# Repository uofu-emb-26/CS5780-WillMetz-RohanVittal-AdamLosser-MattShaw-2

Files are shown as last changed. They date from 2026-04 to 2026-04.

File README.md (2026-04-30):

# CS5780 Final Project
# Nixie Tube Sound Meter

## Rohan Vittal, Will Metz, Adam Losser, and Matt Shaw 

A nixie tube driver that displays real-time microphone loudness as a percentage (0–100) across four ZM1000 nixie tubes. Audio is sampled via an onboard microphone through the STM32's ADC, processed into a loudness percentage, and transmitted over UART to a PC while simultaneously driving the nixie display.

## System Overview:
The system consists of three physical boards:

- STM32F072 Discovery — microcontroller, ADC microphone input, UART output, GPIO drive
- Custom PCB — contains K155ID1 (К155ИД1) BCD driver ICs, HV power distribution, and connectors
- [HV Power Board](https://ebay.us/m/Hubveg) — MAX1771 boost converter (160–210V output), 5V logic input
See [BOM](./BOM.md) for a detailed list of components.

The STM32 extracts digits from the loudness percentage and writes 4-bit BCD values to GPIO pins. Each set of 4 GPIO pins drives one K155ID1 BCD decoder IC, which selects the corresponding cathode on each ZM1000 tube. The anode of each tube is supplied with ~170V.

## Software: 
[mic_test](./mic_test/) contains the code that runs on the STM32. To flash, connect the STM32 discovery to USB, and use the cmake command

```bash
cmake --build build --target mic_test
```
### Software Structure
| File | Description |
|---|---|
| `main.c` | Main loop — ADC sampling, smoothing, UART transmit, nixie write |
| `nixie_drivers.c` | Digit extraction, BCD remapping, GPIO write |
| `adc_mic.c` | ADC initialisation and peak-to-peak measurement |
| `uart.c` | UART3 initialisation and byte transmit |
| `board.c` | SysTick, delay, LED bar (unused) |
| `stm32f0xx_it.c` | SysTick interrupt handler |

### GPIO Pin mappings: 
| Tube | MSB | — | — | LSB |
|---|---|---|---|---|
| Tube 4 (hundreds) | PC9 | PC8 | PC7 | PC6 |
| Tube 3 (tens) | PA11 | PA10 | PA9 | PA8 |
| Tube 2 (ones) | PB11 | PB10 | PB9 | PB8 |
| Tube 1 (tenths) | PB7 | PB6 | PB5 | PB4 |

### BCD Remapping

Due to physical wiring errors on the PCB, a lookup table in firmware remaps intended digits to the correct GPIO pattern:

```c
static const uint8_t digit_map[10] = {
    0b1101, // 0
    0b0001, // 1
    0b1001, // 2
    0b0000, // 3
    0b1110, // 4
    0b0110, // 5
    0b1010, // 6
    0b0010, // 7
    0b1000, // 8
    0b0100  // 9
};
```

## Hardware Notes

- **HV polarity** — the eBay HV power board has reversed polarity output terminals. Verify with a multimeter before connecting to the PCB.
- **HV and logic ground** — must be tied to a common ground, either through the screw terminal or using a breadboard. Separate grounds will prevent cathode current return and the tube will not display any digit.
- **Primer pin** — the ZM1000 primer pin is left floating. A 10MΩ resistor to the anode is recommended per the datasheet for strobed applications but is not required for basic DC operation.
- **USB power** — the micro-USB connector footprint on the PCB was incorrect. It is more reliable to attach 5V power directly by soldering a wire or header on in lieu of the microUSB. 

[fixedSN74141N](./fixedSN74141N/) is a converted KiCAD footprint for the TI SN74141N IC (Identical to the Soviet К155ИД1). 

[nixie_driver](./nixie_driver/) is the KiCAD project for our custom PCB. It takes a 170VDC and 5VDC input, as well as 16 GPIOs for BCD number input. Note that the high voltage and 5V side need to share a common grounding.

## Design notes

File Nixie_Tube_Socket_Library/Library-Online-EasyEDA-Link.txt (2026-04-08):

Library can be found here: https://bit.ly/EasyEDA-SOCKET-LIB

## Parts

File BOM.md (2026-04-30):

# Nixie Tube Driver — Bill of Materials

## Active Components

|Ref  |Description |Value / Part |Qty|Package  |Notes |
|-----|---|---|---|---|---|
|U1 |HV DC-DC Boost Module |MAX1771 |1  |Module |5V in → 170V out|
|U2–U5|BCD-to-Decimal Nixie Driver|SN74141 or K155ID1|4  |DIP-16 |One per tube |
|MCU  |Microcontroller Board |STM32 Discovery |1  |Dev board|Already owned |

-----

## Passive Components

|Ref  |Description |Value |Qty|Package |Notes |
|-----|---|---|---|---|---|
|R1–R4|Anode current-limiting resistor|12kΩ, 1W  |4  |Through-hole or 2512 SMD |1W rating for power dissipation at 170V. One per tube anode.|
|C1–C4|VCC decoupling cap per SN74141 |100nF, 50V|4  |0805 SMD or through-hole |Place as close to each IC VCC pin as possible |
|C7 |HV output decoupling |10µF, 250V|1  |Electrolytic, rated >200V|On 170V rail, near anode resistors |

-----

## Connectors 

|Ref |Description |Part |Qty|Notes |
|---|---|---|---|---|
|J1 |USB input connector|USB  Micro-B |1  |5V power input to PCB |
|J2 |STM32 GPIO header  |2.54mm pin header |1  |16-pin minimum (4 pins × 4 tubes) |
|J3 |HV test point |2-pin header or TP pad |1  |For bench verification of 170V rail |
|J4 |HV input screw terminal | 1x2 3.5mm screw terminal | 1 | |
|J5-J23 | Pin sockets| 1x5 and 1x2 2.54mm pin sockets| 8 ea. | Sockets for nixie tubes|

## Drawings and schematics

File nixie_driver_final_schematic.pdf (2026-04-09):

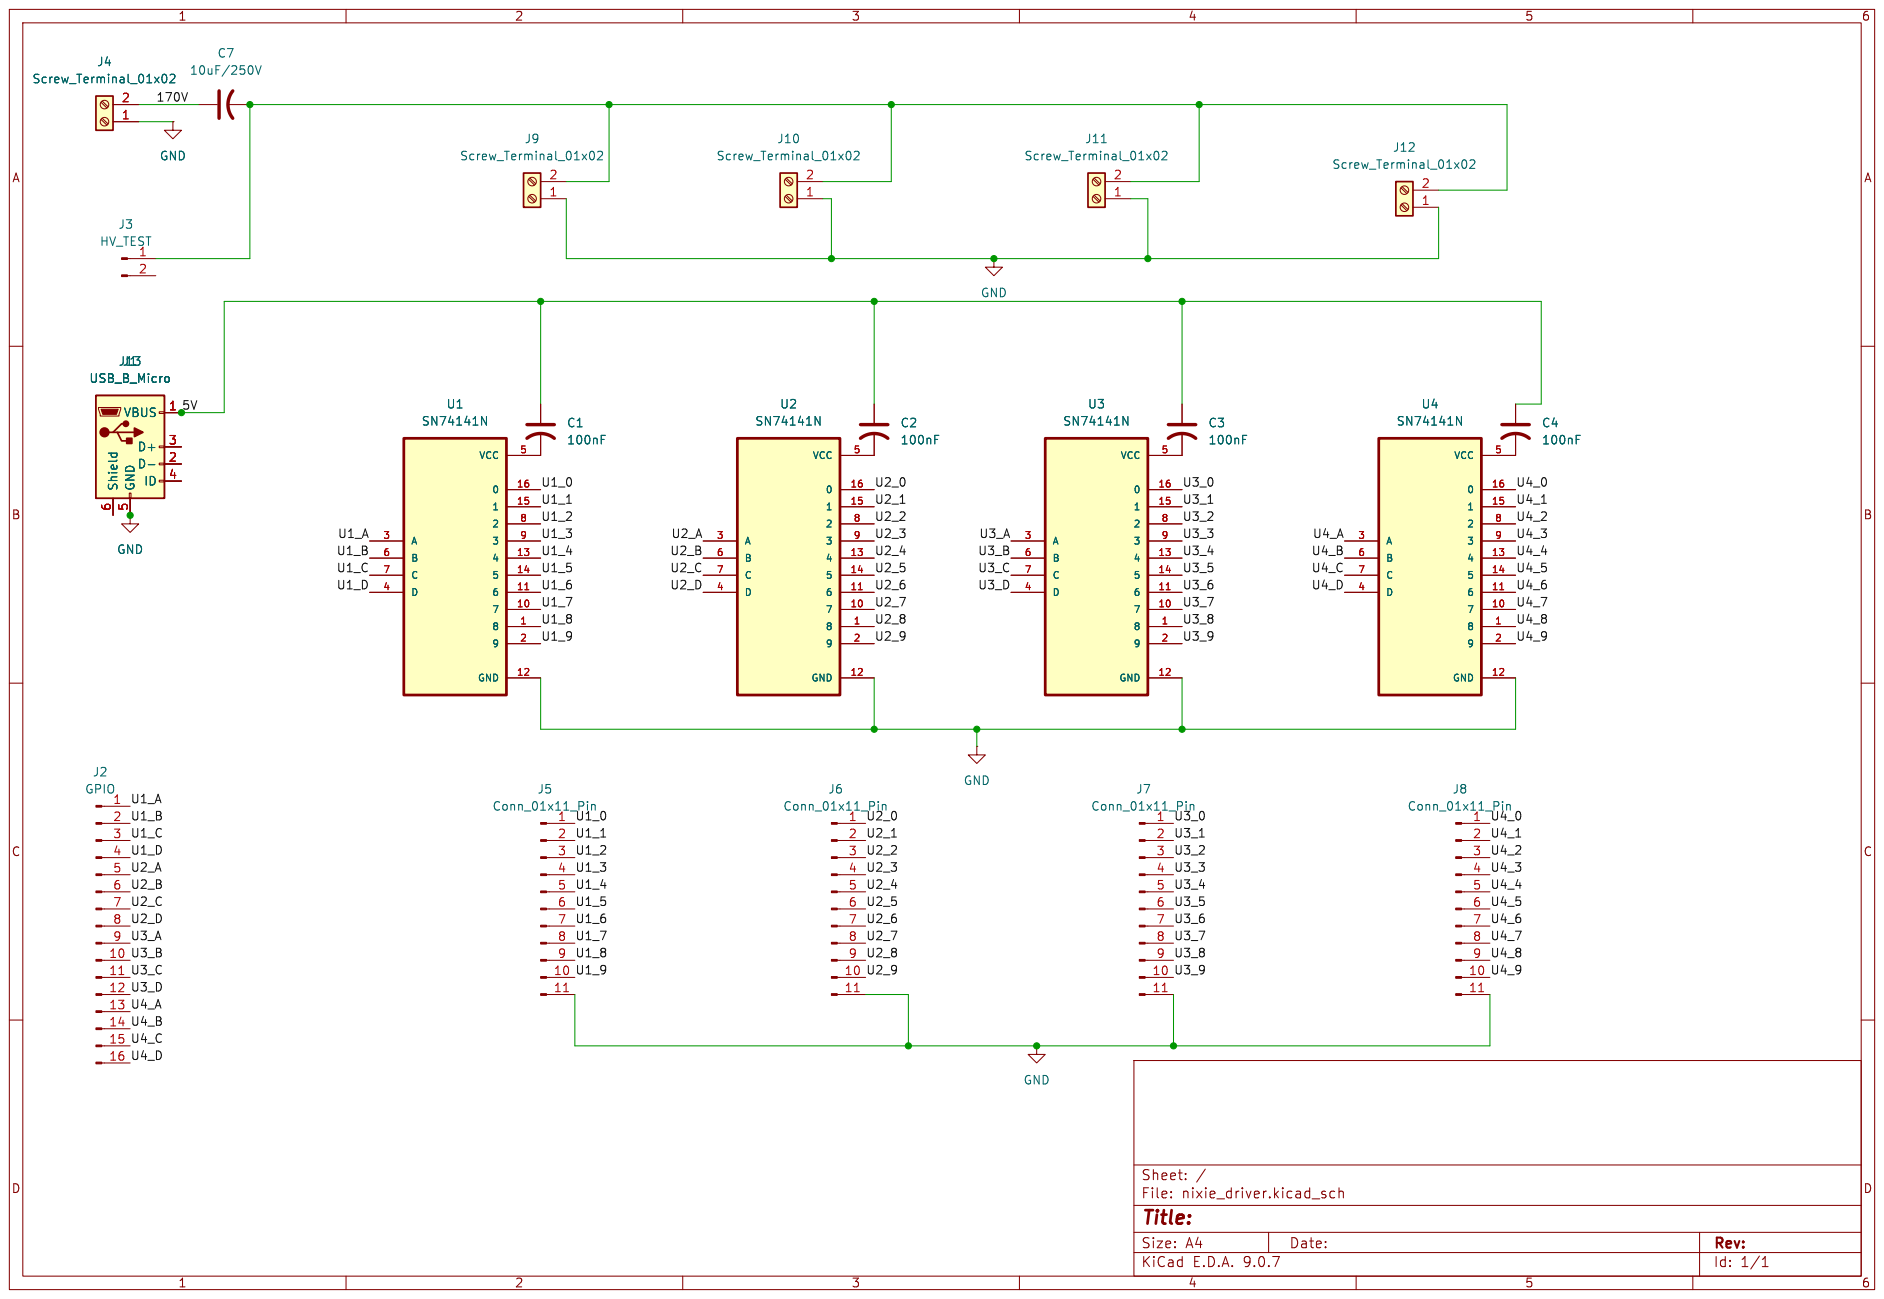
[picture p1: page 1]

Id: 1/1 Title: File: nixie_driver.kicad_sch Sheet: / Shield

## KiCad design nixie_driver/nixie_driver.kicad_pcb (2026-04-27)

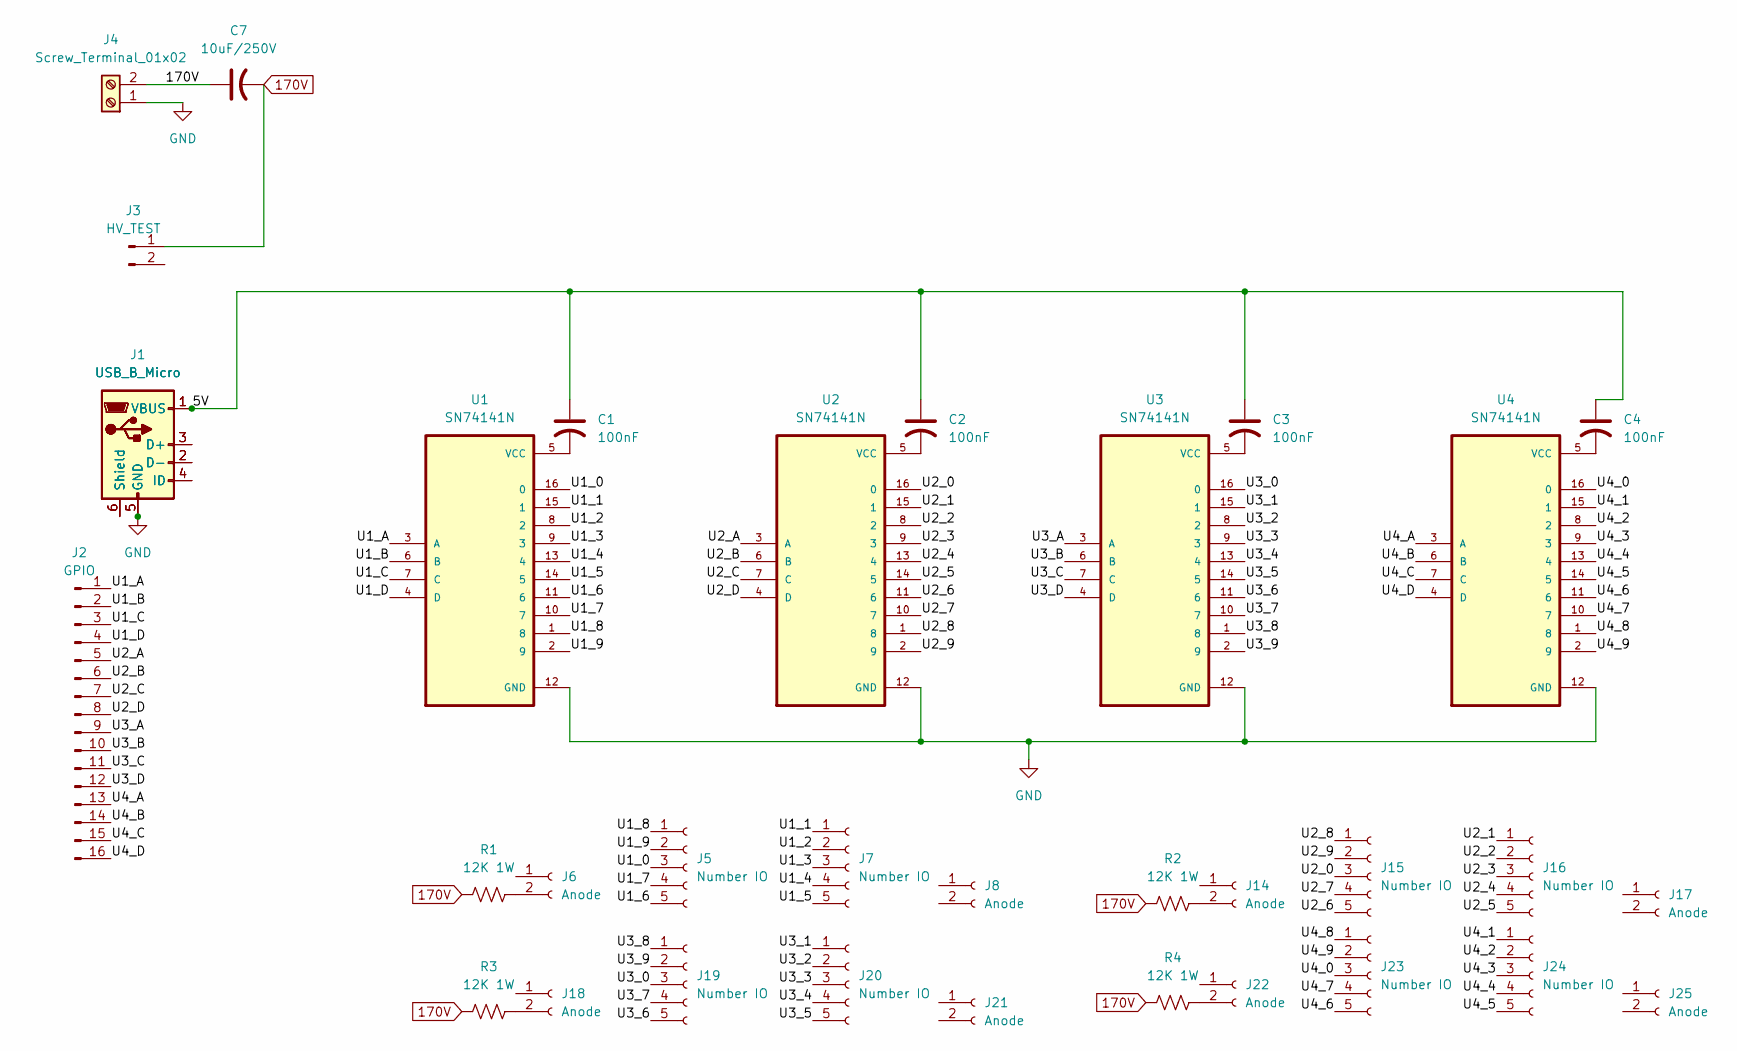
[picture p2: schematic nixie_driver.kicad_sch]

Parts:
C1, C2, C3, C4: 100nF; C_0805_2012Metric_Pad1.18x1.45mm_HandSolder
C7: 10uF/250V; CP_Radial_D8.0mm_P3.50mm
J1: USB_B_Micro; USB_Micro-AB_Molex_47590-0001
J2: GPIO; PinHeader_1x16_P2.54mm_Vertical
J3: HV_TEST; PinHeader_1x02_P2.54mm_Vertical
J4: Screw_Terminal_01x02; TerminalBlock_MetzConnect_Type011_RT05502HBLC_1x02_P5.00mm_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
J5, J7, J15, J16, J19, J20, J23, J24: Number IO; PinSocket_1x05_P2.54mm_Vertical
J6, J8, J14, J17, J18, J21, J22, J25: Anode; PinSocket_1x02_P2.54mm_Vertical
J13: USB_B_Micro
R1, R2, R3, R4: 12K 1W; R_Axial_DIN0414_L11.9mm_D4.5mm_P20.32mm_Horizontal
U1, U2, U3, U4: SN74141N; DIP762W46P254L2134H508Q16

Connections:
170V: C7.1, C7.2, J3.1, J4.2, R1.1, R2.1, R3.1, R4.1
/5V: C1.1, C2.1, C3.1, C4.1, J1.1 (VBUS), J13.1 (VBUS)
/U1_0: J5.3, U1.16 (0)
/U1_1: J7.1, U1.15 (1)
/U1_2: J7.2, U1.8 (2)
/U1_3: J7.3, U1.9 (3)
/U1_4: J7.4, U1.13 (4)
/U1_5: J7.5, U1.14 (5)
/U1_6: J5.5, U1.11 (6)
/U1_7: J5.4, U1.10 (7)
/U1_8: J5.1, U1.1 (8)
/U1_9: J5.2, U1.2 (9)
/U1_A: J2.1, U1.3 (A)
/U1_B: J2.2, U1.6 (B)
/U1_C: J2.3, U1.7 (C)
/U1_D: J2.4, U1.4 (D)
/U2_0: J15.3, U2.16 (0)
/U2_1: J16.1, U2.15 (1)
/U2_2: J16.2, U2.8 (2)
/U2_3: J16.3, U2.9 (3)
/U2_4: J16.4, U2.13 (4)
/U2_5: J16.5, U2.14 (5)
/U2_6: J15.5, U2.11 (6)
/U2_7: J15.4, U2.10 (7)
/U2_8: J15.1, U2.1 (8)
/U2_9: J15.2, U2.2 (9)
/U2_A: J2.5, U2.3 (A)
/U2_B: J2.6, U2.6 (B)
/U2_C: J2.7, U2.7 (C)
/U2_D: J2.8, U2.4 (D)
/U3_0: J19.3, U3.16 (0)
/U3_1: J20.1, U3.15 (1)
/U3_2: J20.2, U3.8 (2)
/U3_3: J20.3, U3.9 (3)
/U3_4: J20.4, U3.13 (4)
/U3_5: J20.5, U3.14 (5)
/U3_6: J19.5, U3.11 (6)
/U3_7: J19.4, U3.10 (7)
/U3_8: J19.1, U3.1 (8)
/U3_9: J19.2, U3.2 (9)
/U3_A: J2.9, U3.3 (A)
/U3_B: J2.10, U3.6 (B)
/U3_C: J2.11, U3.7 (C)
/U3_D: J2.12, U3.4 (D)
/U4_0: J23.3, U4.16 (0)
/U4_1: J24.1, U4.15 (1)
/U4_2: J24.2, U4.8 (2)
/U4_3: J24.3, U4.9 (3)
/U4_4: J24.4, U4.13 (4)
/U4_5: J24.5, U4.14 (5)
/U4_6: J23.5, U4.11 (6)
/U4_7: J23.4, U4.10 (7)
/U4_8: J23.1, U4.1 (8)
/U4_9: J23.2, U4.2 (9)
/U4_A: J2.13, U4.3 (A)
/U4_B: J2.14, U4.6 (B)
/U4_C: J2.15, U4.7 (C)
/U4_D: J2.16, U4.4 (D)
GND: J1.5 (GND), J4.1, J13.5 (GND), U1.12 (GND), U2.12 (GND), U3.12 (GND), U4.12 (GND)
unnamed: J1.3 (D+), J13.3 (D+)
unnamed: J1.2 (D-), J13.2 (D-)
unnamed: J1.4 (ID), J13.4 (ID)
unnamed: J1.6 (Shield), J13.6 (Shield)
unnamed: J6.2, R1.2
unnamed: J14.2, R2.2
unnamed: J18.2, R3.2
unnamed: J22.2, R4.2
unnamed: C1.2, U1.5 (VCC)
unnamed: C2.2, U2.5 (VCC)
unnamed: C3.2, U3.5 (VCC)
unnamed: C4.2, U4.5 (VCC)

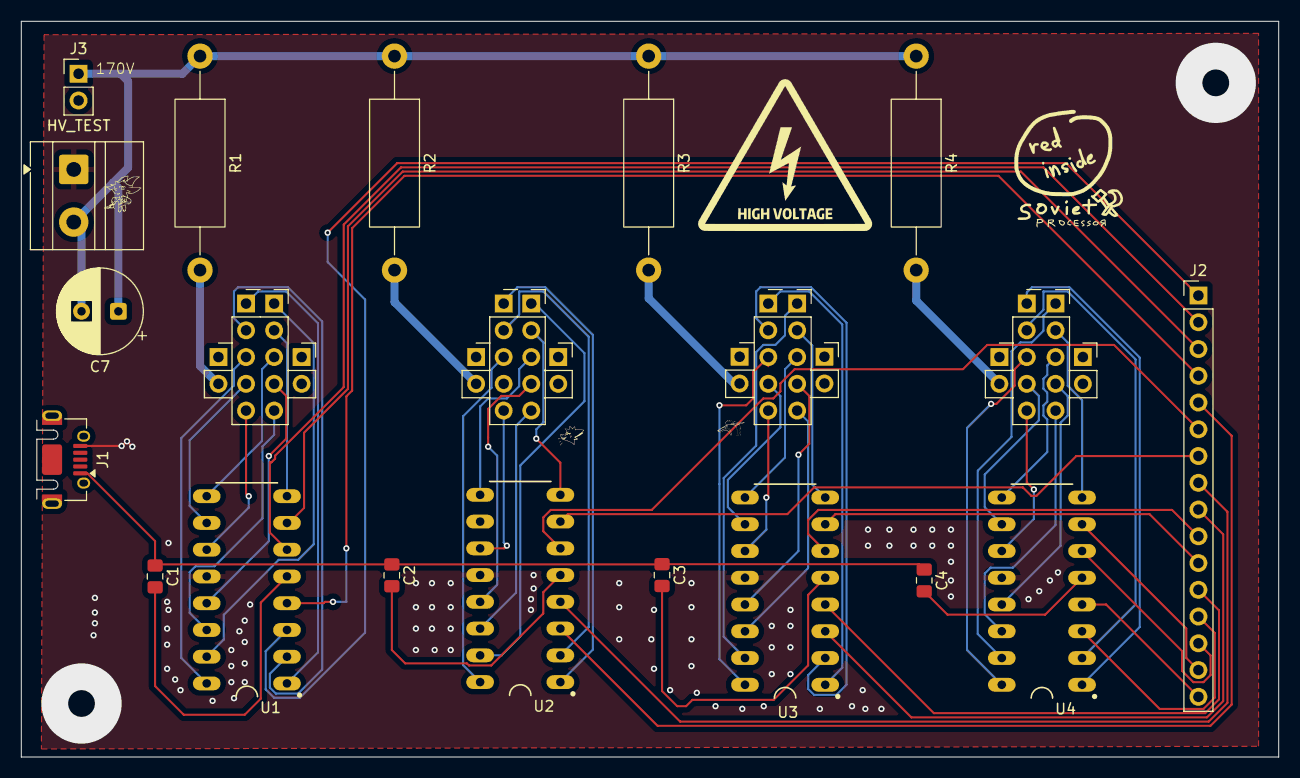
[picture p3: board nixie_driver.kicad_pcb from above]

Board: 2 copper layers, 119.4 x 69.8 mm, 33 parts (0 on the bottom side), 67 nets.

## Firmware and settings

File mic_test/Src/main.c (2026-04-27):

#include <stdint.h>
#include "adc_mic.h"
#include "app_config.h"
#include "board.h"
#include "stm32f0xx.h"
#include "stm32f0xx_hal.h"
#include "stm32f0xx_hal_gpio.h"
#include "uart.h"
#include "nixie_drivers.h"

static uint16_t apply_noise_floor(uint16_t level)
{
    if (level <= MIC_NOISE_FLOOR_COUNTS)
    {
        return 0u;
    }

    return (uint16_t)(level - MIC_NOISE_FLOOR_COUNTS);
}

static uint8_t level_to_led_count(uint16_t level)
{
    if (level >= MIC_LED4_THRESHOLD)
    {
        return 4u;
    }
    if (level >= MIC_LED3_THRESHOLD)
    {
        return 3u;
    }
    if (level >= MIC_LED2_THRESHOLD)
    {
        return 2u;
    }
    if (level >= MIC_LED1_THRESHOLD)
    {
        return 1u;
    }
    return 0u;
}

volatile uint16_t g_mic_peak_to_peak_raw = 0u;
volatile uint16_t g_mic_peak_to_peak_filtered = 0u;
volatile uint16_t g_mic_level_smoothed = 0u;
volatile uint8_t g_led_count = 0u;

int main(void)
{
    uint16_t smoothed_level = 0u;

    board_init();
    mic_init();

    HAL_Init();
    uart_init();
    init_tube_gpios();

    uint8_t previous_percentage = 0; // hold the previously transmitted value


    

    while (1)
    {

        uint8_t percentage_buffer[BUFFER_SIZE] = {0};

        for (uint32_t buffer_count = 0; buffer_count < BUFFER_SIZE; buffer_count++) // loop to fill buffer with 20 values before transmitting
        {

        uint16_t raw_level = mic_measure_peak_to_peak(MIC_SAMPLE_WINDOW);
        uint16_t filtered_level = apply_noise_floor(raw_level);

        smoothed_level = (uint16_t)(((uint32_t)smoothed_level * APP_SMOOTHING_NUMERATOR +
                                     (uint32_t)filtered_level) /
                                    APP_SMOOTHING_DENOMINATOR);

        g_mic_peak_to_peak_raw = raw_level;
        g_mic_peak_to_peak_filtered = filtered_level;
        if (filtered_level > g_mic_level_smoothed) {
            g_mic_level_smoothed = filtered_level;
        } else {
            g_mic_level_smoothed = (uint16_t)(((3u * g_mic_level_smoothed) + filtered_level) / 4u);
        }
        g_led_count = level_to_led_count(smoothed_level);

        //board_led_bar_set(g_led_count);

        // convert filtered level into the range 0 to 100 (a loudness percentage)
            uint32_t interpolation_input = (uint32_t)filtered_level; // convert to a 32 bit integer to prevent overflow when doing operations

            // cap our inputs so they always result in an output in the range 0 to 100
            if (interpolation_input > 1800)
            {
                interpolation_input = 1800;
            }

            if (interpolation_input < 64)
            {
                interpolation_input = 64;
            }

            // calculate the percentage
            uint8_t percentage = (uint8_t)(((interpolation_input - 64)*100)/1736);
            percentage_buffer[buffer_count] = percentage;

        }

        // get the average of the percentage buffer
        uint8_t average_percentage = get_array_average(percentage_buffer,BUFFER_SIZE);

        // check if the difference between the current percentage and the previous percentage is large enough to warrant transmitting
        int32_t difference = (int32_t)previous_percentage - (int32_t)average_percentage;

        // get the absolute value of the difference
        if (difference < 0)
        {
            difference = -1 * difference;
        }

        if (difference > UPDATE_THRESHOLD)
        {

            // transmit the loudness percentage via UART
            transmit_byte(average_percentage);
            write_int_to_tubes((uint16_t) average_percentage);

            // store the current percentage as the last transmitted percentage
            previous_percentage = average_percentage;

        }

        board_delay_ms(APP_UPDATE_PERIOD_MS);

    }

}



uint8_t get_array_average(uint8_t array[],uint32_t array_size)
{
    uint32_t sum = 0;
    uint32_t avg = 0;
    for (uint32_t i = 0; i < array_size; i++)
    {
        sum += array[i];
    }

    avg = sum/array_size;

    return (uint8_t)avg;
}

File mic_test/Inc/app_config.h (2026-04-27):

#ifndef APP_CONFIG_H
#define APP_CONFIG_H

#include <stdint.h>
#include "stm32f0xx.h"

/*
 * Microphone input configuration.
 */
#define MIC_ADC_GPIO                  GPIOA
#define MIC_ADC_GPIO_CLOCK_ENABLE()   do { RCC->AHBENR |= RCC_AHBENR_GPIOAEN; } while (0)
#define MIC_ADC_PIN_INDEX             4u
#define MIC_ADC_PIN_MASK              (1u << MIC_ADC_PIN_INDEX)
#define MIC_ADC_CHANNEL_SELECT        ADC_CHSELR_CHSEL4

/*
 * Peak-to-peak measurement settings.
 */
#define MIC_SAMPLE_WINDOW             64u
#define MIC_NOISE_FLOOR_COUNTS        120u
#define MIC_LED1_THRESHOLD            200u
#define MIC_LED2_THRESHOLD            500u
#define MIC_LED3_THRESHOLD            1000u
#define MIC_LED4_THRESHOLD            1800u

/*
 *   MIC_NOISE_FLOOR_COUNTS = 220u
 *   MIC_LED1_THRESHOLD     = 400u
 *   MIC_LED2_THRESHOLD     = 850u
 *   MIC_LED3_THRESHOLD     = 1500u
 *   MIC_LED4_THRESHOLD     = 2600u
 */

/* UI update rate and smoothing. */
#define APP_UPDATE_PERIOD_MS          25u
#define APP_SMOOTHING_NUMERATOR       7u
#define APP_SMOOTHING_DENOMINATOR     8u
#define BUFFER_SIZE                   200u
#define UPDATE_THRESHOLD              5u

#endif /* APP_CONFIG_H */

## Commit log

2026-03-26 added pcb and schema
    [nixie_driver.kicad_pcb, nixie_driver.kicad_sch]
2026-04-03 mic volume to led code
2026-04-08 redoing stuff
    [nixie_driver.kicad_sch]
2026-04-08 fixed deisgn
    [nixie_driver.kicad_sch]
2026-04-09 mostly done
    [nixie_driver.kicad_sch]
2026-04-09 more label
    [nixie_driver.kicad_sch]
2026-04-09 schematic done
    [nixie_driver.kicad_sch]
2026-04-10 new PCB
    [nixie_driver.kicad_pcb, nixie_driver.kicad_sch]
2026-04-10 polishing of pcb some issues still
    [nixie_driver.kicad_pcb]
2026-04-22 finished nixie driver code and uart code
2026-04-27 fixed minor bugs in lookup table
    [main.c, nixie_drivers.c]
2026-04-27 updated pcb
    [nixie_driver.kicad_pcb, nixie_driver.kicad_sch]
2026-04-27 fixed connection on chip3
    [nixie_driver-B_Cu.gbr, nixie_driver-B_Mask.gbr, nixie_driver-B_Paste.gbr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]
2026-04-30 update bom
